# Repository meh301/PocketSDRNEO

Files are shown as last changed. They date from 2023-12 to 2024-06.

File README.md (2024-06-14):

# **Pocket SDR - An Open-Source GNSS SDR, ver. 2.1 NEO**

## **This project is now archived**
The NEO variant of the v2.1 PocketSDR was only meant to be a short-term solution for increasing international interest in the open source project. The official PocketSDR has now been updated to include USB-C, as well as several design improvements. Please refer to the official Github: https://github.com/tomojitakasu/PocketSDR

---

The NEO* variant of Professor 高須知二 (Tomoji Takasu)'s PocketSDR replaces the micro-B connector with type-C, fixes the LDO routing, adds an 0603 100 Ohm resistor at the output of the RF power divider as per the datasheet, and finally provides the option of either using a pin header or a Littlefuse MICROSMD010 for antenna power delivery.

Please note that due to the use of a type-C connector, the dimensions of the board are slightly larger than the original design.

## **Overview**

Pocket SDR is an open-source GNSS (Global Navigation Satellite System) receiver
based on SDR (software defined radio) technology. It consists of a RF front-end
device, some utilities for the device and GNSS-SDR APs (application programs)
written in Python and C. It supports almost all signals for GPS, GLONASS,
Galileo, QZSS, BeiDou, NavIC and SBAS.

The RF front-end device consists of 2 CH Maxim MAX2771 GNSS RF front-end IC
(LNA, mixer, filter, ADC, frequency synthesizer) and Cypress EZ-USB FX2LP USB
2.0 controller to connect to host PCs. The front-end CH1 is dedicated for GNSS
L1 band (1525 - 1610 MHz) and CH2 is for GNSS L2/L5/L6 band (1160 - 1290 MHz).
The frequency of the reference oscillator (TCXO) is 24.000 MHz and ADC sampling
frequency can be configured up to 24 MHz.

Pocket SDR contains some utility programs for the RF front-end device to
configure the device, capture and dump the digitized IF (inter-frequency) data.
These supports Windows, Linux and other environments.

Pocket SDR also provides GNSS-SDR APs to show the PSD (power spectrum density)
of captured IF data, search the GNSS signals, track these signals and decode
navigation data in them. The supported GNSS signals are as follows. These APs
are written in Python by very compact way. They are easily modified by users
to add user's unique algorithms.

GPS: L1C/A, L1CP, L1CD, L2CM, L5I, L5Q, GLONASS: L1C/A, L2C/A, L3OCD, L3OCP,
Galileo: E1B, E1C, E5aI, E5aQ, E5bI, E5bQ, E6B, E6C, QZSS: L1C/A, L1C/B, L1CP,
L1CD, L1S, L2CM, L5I, L5Q, L5SI, L5SQ, L6D, L6E, BeiDou: B1I, B1CP, B1CD, B2I,
B2aD, B2aP, B2bI, B3I, NavIC: L5-SPS, SBAS: L1C/A, L5I, L5Q

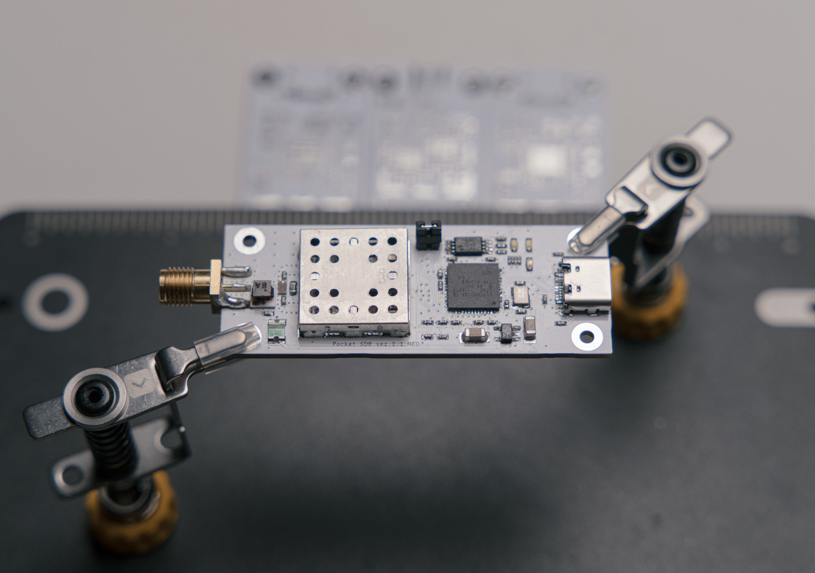
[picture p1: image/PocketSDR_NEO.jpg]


The introduction of Pocket SDR is shown in the following slides.

T.Takasu, An Open Source GNSS SDR: Development and Application, IPNTJ Next GNSS
Technology WG, Feb 21, 2022
(https://gpspp.sakura.ne.jp/paper2005/IPNTJ_NEXTWG_202202.pdf)

---

## **Package Structure**

```
PocketSDR --+-- bin     Pocket SDR utilities and APs binary programs for Windows
            +-- app     Pocket SDR utilities and APs source programs
            +-- src     Pocket SDR library source programs
            +-- python  Pocket SDR Python scripts
            +-- lib     External library for utilities and APs
            +-- conf    Configuration files for device settings
            +-- driver  Windows driver for EZ-USB FX2LP/FX3 (cyusb3.sys) ([4])
            +-- doc     Documents (ref {1], [2])
            +-- FW      Firmware source programs and images
            |   +-- cypress  Cypress libraries for EZ-USB firmware development
            |                (ref [4])
            +-- HW      Pocket SDR RF frontend CAD data and parts list
            |           (*.brd and *.sch are for Eagle, *.f3d is for Fusion 360)
            +-- image   Image files for documents
            +-- sample  Sample digital IF data captured by Pocket SDR
            +-- test    Test codes
```

---

## **Installation for Windows**

- Extract PocketSDR.zip to an appropriate directory <install_dir>.

- Attach Pocket SDR RF frontend to PC via USB cable.

- Install USB driver (CYUSB) for Pocket SDR RF frontend according to
  PocketSDR\driver\readme.txt.

- Add the Pocket SDR binary programs path (<install_dir>\PocketSDR\bin) to
  the command search path (Path) of Windows environment variables.

- Add the Pocket SDR Python scripts path (<install_dir>\PocketSDR\python) to
  the command search path (Path) of Windows environment variables.

- To rebuild the binary programs, you need MinGW64 and libusb-1.0 library.
  Refer MSYS2 (https://www.msys2.org/) for details.

- In MinGW64 environment, you need fftw3 library. To install fftw3 library.

```
    $ pacman -S mingw-w64-x86_64-fftw
```

---

## **Installation for Linux**

- Extract PocketSDR.zip to an appropriate directory <install_dir>.

```
    $ unzip PocketSDR.zip
```

- Install libusb-1.0 developtment package. For Ubuntu:

```
    $ sudo apt install libusb-1.0-0-dev
```

- Install libfftw3 developtment package. For Ubuntu:

```
    $ sudo apt install libfftw3-dev
```

- Move to the library directory, build libraries.

```
    $ cd <install_dir>/lib/build
    $ make
    $ make install
```

- Move to the source program directory, build utilities and APs.

```
    $ cd <install_dir>/app
    $ make
    $ make install
```

- Add the Pocket SDR binary programs path (<install_dir>/PocketSDR/bin) to
  the command search path.

- Usually you need to have root permission to access USB devices. So you add
  sudo to execute pocket_conf, pocket_dump like:

```
   $ sudo pocket_conf ../conf/pocket_L1L6_12MHz.conf
   $ sudo pocket_dump -t 10 ch1.bin ch2.bin
```

---

## **Utility Programs for RF frontend**

Pocket SDR contains the following utility programs.

- **pocket_conf**: SDR device configurator
- **pocket_scan**: Scan and list USB Devices
- **pocket_dump**: Capture and dump digital IF data of SDR device

For details, refer comment lines in src/pocket_conf.c, src/pocket_scan.c,
src/pocket_dump.c.

---

## **GNSS-SDR APs (Application Programs)**

Pocket SDR contains the following application programs for GNSS-SDR.

- **pocket_psd.py** : Plot PSD and histgrams of digital IF data
- **pocket_acq.py** : GNSS signal acquisition in digital IF data
- **pocket_trk.py** : GNSS signal tracking and navigation data decoding in digital IF data
- **pocket_snap.py**: Snapshot positioning with digital IF data
- **pocket_plot.py**: Plot GNSS signal tracking log by pocket_trk.py
- **pocket_acq** : C-version of pocket_acq.py (w/o graph plots)
- **pocket_trk** : C-version of pocket_trk.py (w/o graph plots)

For details, refer comment lines in python/pocket_psd.py, python/pocket_acq.py,
python/pocket_trk.py, python/pocket_snap.py and python/pocket_plot.py. You need
Python 3, Numpy, Scipy and matplotlib to execute Python scripts. pocket_trk.py
uses external shared libraries of LIBFEC [5] and RTKLIB [6] in lib/ directory.
These were built for Windows (64bit) and Linux for x86_64 CPU.

---

## **Execution Examples of Utility Programs and GNSS-SDR APs**

```
    $ pocket_conf
    ...
    $ pocket_conf conf/pocket_L1L6_12MHz.conf
    Pocket SDR device settings are changed.

    $ pocket_dump -t 5 ch1.bin ch2.bin
      TIME(s)    T   CH1(Bytes)   T   CH2(Bytes)   RATE(Ks/s)
          5.0    I     59768832  IQ    119537664      11922.8

    $ pocket_psd.py ch1.bin -f 12 -h
    $ pocket_acq.py ch1.bin -f 12 -fi 3 -sig L1CA -prn 1-32,193-199
    PRN   1: SIG= L1CA, COFF=  0.12817 ms, DOP=  3500 Hz, C/N0= 37.4 dB-Hz
    PRN   2: SIG= L1CA, COFF=  0.85242 ms, DOP= -3500 Hz, C/N0= 36.8 dB-Hz
    PRN   3: SIG= L1CA, COFF=  0.39400 ms, DOP= -2000 Hz, C/N0= 37.0 dB-Hz
    PRN   4: SIG= L1CA, COFF=  0.96692 ms, DOP=  2000 Hz, C/N0= 44.7 dB-Hz
    ...
    $ pocket_acq.py ch1.bin -f 12 -fi 3 -sig L1CA -prn 26

    $ pocket_acq.py ch1.bin -f 12 -fi 3 -sig L1CA -prn 26 -3d

    $ pocket_acq.py ch2.bin -f 12 -sig L6D -prn 194 -p

    $ pocket_trk.py L1_24M.bin -prn 1-32 -f 24 -fi 6
	  TIME(s)   SIG  PRN  STATE   LOCK(s)  C/N0 (dB-Hz)        COFF(ms)   DOP(Hz)   ADR(cyc)  SYNC #NAV #ERR
	    1.550  L1CA    1   LOCK     1.539  42.5 ||||||||      0.8017699    3218.8     4949.3  ---     0    0
	    0.011  L1CA    2   IDLE     0.000   0.0               0.0000000       0.0        0.0  ---     0    0
	    0.011  L1CA    3   IDLE     0.000   0.0               0.0000000       0.0        0.0  ---     0    0
	    0.011  L1CA    4   IDLE     0.000   0.0               0.0000000       0.0        0.0  ---     0    0
	    0.011  L1CA    5   IDLE     0.000   0.0               0.0000000       0.0        0.0  ---     0    0
	    0.011  L1CA    6   IDLE     0.000   0.0               0.0000000       0.0        0.0  ---     0    0
	    1.550  L1CA    7   LOCK     1.539  45.7 ||||||||||    0.6995059     582.8      901.5  ---     0    0
	    1.550  L1CA    8   LOCK     1.539  47.6 |||||||||||   0.0733506    -777.2    -1196.8  ---     0    0
	    0.011  L1CA    9   IDLE     0.000   0.0               0.0000000       0.0        0.0  ---     0    0
	    1.550  L1CA   10   LOCK     1.539  38.6 |||||         0.8658548      -6.2       -9.4  ---     0    0
	...
    $ pocket_trk.py L1_24M.bin -prn 194 -sig L1CA -f 24 -fi 6 -log trk.log  -p
    ...
    $ pocket_trk.py L5_24M.bin -prn 13 -sig E5AI -f 24 -log trk.log -p -ts 0.2
    ...
```









---

## **Rebuild F/W and Write F/W Image to Pocket SDR RF frontend**

- Install Cypress EZ-USB FX2LP Development Kit (ref [4]) to a Windows PC. As
  default, it is installed to C:\Cypress and C:\Keil.

- Execute Keil uVision2 (C:\Keil\UV2\uv2.exe).

- Execute Menu Project - Open Project, select <install_dir>\PocketSDR\FW\pocket_fw.Uv2>
  and open the project.

- Execute Menu Project - Rebuild all target files and you can get a F/W image
  as <install_dir>\PocketSDR\FW\pocket_fw.iic.

- Attach Pocket SDR RF frontend via USB cable to the PC.

- Execute USB Control Center (C:\Cypress\USB\CY3684_EZ-USB_FX2LP_DVK\1.1\Windows Applications\
  c_sharp\controlcenter\bin\Release\CyControl.exe).

- Select Cypress FX2LP Sample Device, execute menu Program - FX2 - 64KB EEPROM,
  select the F/W image <install_dir>\PocketSDR\FW\pocket_fw.iic and open it.

- If you see "Programming succeeded." in status bar, the F/W is properly written
  to PocketSDR.

- To use utility programs for Pocket SDR, you need to reinstall WinUSB driver for
  Pocket SDR. Refer "Installation for Windows" above.

---

## **References**

[1] Maxim integrated, MAX2771 Multiband Universal GNSS Receiver, July 2018

[2] Cypress, EZ-USB FX2LP USB Microcontroller High-Speed USB Peripheral
Controller, Rev. AB, December 6, 2018

[3] (deleted)

[4] Cypress, CY3684 EZ-USB FX2LP Development Kit
(https://www.cypress.com/documentation/development-kitsboards/cy3684-ez-usb-fx2lp-development-kit)

[5] https://github.com/quiet/libfec

[6] https://github.com/tomojitakasu/RTKLIB

---

## **History**

- 2021-10-20 0.1 1st draft version
- 2021-10-25 0.2 Add Rebuild F/W and Write F/W Image to PocketSDR
- 2021-12-01 0.3 Add and modify Python scripts
- 2021-12-25 0.4 Add and modify Python scripts
- 2022-01-05 0.5 Fix several problems.
- 2022-01-13 0.6 Add and modify Python scripts
- 2022-02-15 0.7 Improve performance, Add some Python scripts.
- 2022-07-08 0.8 Add C-version of pocket_acq.py and pocket_trk.py.

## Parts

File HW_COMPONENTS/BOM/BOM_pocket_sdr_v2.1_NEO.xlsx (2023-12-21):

DIGIKEY
Index | Manufacturer Part Number | Manufacturer Name | Description | Availability | Stock Status | Attrition % | Requested Quantity 1 | Pack Quantity 1 | Pack Type 1 | Digi-Key Part Number 1 | Unit Price 1 | Extended Price 1 | Minimum Order Quantity 1 | Customer Reference | Requested Part Number | Lead Weeks | Datasheet | Reference Designator | US Import Tariff | Note | Part Status | RoHS Status | Moisture Sensitivity Level (MSL) | ECCN | HTSUS | Country of Origin | Environmental Information | Original Part numbers | Image
1 | CY7C68013A-56LTXCT | Infineon Technologies | IC MCU USB PHERIPH FX2LP 56VQFN | 11046 | In Stock |  | 1 | 1 | Cut Tape (CT) | 448-CY7C68013A-56LTXCT-ND | 1886.00 | ¥1,886 | 1 |  | 428-4634-1-ND | 13 | https://www.infineon.com/dgdl/Infineon-CY7C68013A_CY7C68014A_CY7C68015A_CY7C68016A_EZ-USB_FX2LP_USB_Microcontroller_High-Speed_USB_Peripheral_Controller-DataS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 |  | - |  | Active | ROHS3 Compliant | 3 (168 Hours) | 3A991A3 | 8542.31.0001 | Philippines | https://www.cypress.com/file/199231/download | 428-4634-1-ND | https://mm.digikey.com/Volume0/opasdata/d220001/medias/images/582/56-VQFN-LT.jpg
2 | 24AA128T-I/ST | Microchip Technology | IC EEPROM 128KBIT I2C 8TSSOP | 30456 | In Stock |  | 1 | 1 | Cut Tape (CT) | 24AA128T-I/STCT-ND | 123 | ¥123 | 1 |  | 24AA128T-I/STCT-ND | 4 | https://ww1.microchip.com/downloads/en/DeviceDoc/24AA128-24LC128-24FC128-128K-I2C-Serial-EEPROM-DS.pdf |  | - |  | Active | ROHS3 Compliant | 1 (Unlimited) | EAR99 | 8542.32.0051 | Thailand | https://ww1.microchip.com/downloads/aemDocuments/documents/corporate-responsibilty/environmental/product-regulatory-information/Semiconductor_Prop_65_Statemen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|https://ww1.microchip.com/downloads/aemDocuments/documents/corporate-responsibilty/environmental/product-regulatory-information/Microchip_REACH_Statement.pdf|https://ww1.microchip.com/downloads/aemDocuments/documents/corporate-responsibilty/environmental/product-regulatory-information/Semiconductor_EnvCoC.pdf | 24AA128T-I/STCT-ND | https://mm.digikey.com/Volume0/opasdata/d220001/medias/images/5462/150~C04-086~ST~8.JPG
3 | RP111N331D-TR-FE | Nisshinbo Micro Devices Inc. | IC REG LINEAR 3.3V 500MA SOT23-5 | 9425 | In Stock |  | 1 | 1 | Cut Tape (CT) | 2129-RP111N331D-TR-FECT-ND | 174 | ¥174 | 1 |  | 2129-RP111N331D-TR-FECT-ND | 12 | https://www.nisshinbo-microdevices.co.jp/en/pdf/datasheet/rp111-ea.pdf |  | - |  | Active | ROHS3 Compliant | 1 (Unlimited) | EAR99 | 8542.39.0001 | Japan |  | 2129-RP111N331D-TR-FECT-ND | https://mm.digikey.com/Volume0/opasdata/d220001/medias/images/4376/MFG_SOT-23-5.jpg
4 | 830108340709 | Würth Elektronik | WE-XTAL QUARTZ CRYSTAL 24.0 MHZ; | 124 | In Stock |  | 1 | 1 | Cut Tape (CT) | 1923-830108340709CT-ND | 128 | ¥128 | 1 |  | 1923-830108340709CT-ND | 11 | https://www.we-online.com/catalog/datasheet/830108340709.pdf |  | May apply on shipments to the U.S. |  | Active | ROHS3 Compliant | Not Applicable | EAR99 | 8541.60.0060 | China | https://mm.digikey.com/Volume0/opasdata/d220001/medias/docus/744/Certificate_of_Compliance_ROHS.pdf | 1923-830108340709CT-ND | https://mm.digikey.com/Volume0/opasdata/d220001/medias/images/2832/MFG_XTAL_CFPX-180.jpg
5 | RC0402JR-0715KL | YAGEO | RES 15K OHM 5% 1/16W 0402 | 631681 | In Stock |  | 2 | 2 | Cut Tape (CT) | 311-15KJRCT-ND | 16 | ¥32 | 1 |  | 311-15KJRCT-ND | 18 | https://www.yageo.com/upload/media/product/app/datasheet/rchip/pyu-rc_group_51_rohs_l.pdf |  | May apply on shipments to the U.S. |  | Active | ROHS3 Compliant | 1 (Unlimited) | EAR99 | 8533.21.0030 | Taiwan | https://www.yageo.com/en/Download/Index/certificates#rchip | 311-15KJRCT-ND | https://mm.digikey.com/Volume0/opasdata/d220001/medias/images/4849/13_0402-%281005-metric%29.jpg
6 | RC0402JR-0710KL | YAGEO | RES 10K OHM 5% 1/16W 0402 | 28660058 | In Stock |  | 5 | 5 | Cut Tape (CT) | 311-10KJRCT-ND | 16 | ¥80 | 1 |  | 311-10KJRCT-ND | 18 | https://www.yageo.com/upload/media/product/app/datasheet/rchip/pyu-rc_group_51_rohs_l.pdf |  | - |  | Active | ROHS3 Compliant | 1 (Unlimited) | EAR99 | 8533.21.0030 | Taiwan | https://www.yageo.com/en/Download/Index/certificates#rchip | 311-10KJRCT-ND | https://mm.digikey.com/Volume0/opasdata/d220001/medias/images/4849/13_0402-%281005-metric%29.jpg
7 | RC0402JR-072K2L | YAGEO | RES 2.2K OHM 5% 1/16W 0402 | 1852 | In Stock |  | 2 | 2 | Cut Tape (CT) | 311-2.2KJRCT-ND | 16 | ¥32 | 1 |  | 311-2.2KJRCT-ND | 18 | https://www.yageo.com/upload/media/product/app/datasheet/rchip/pyu-rc_group_51_rohs_l.pdf |  | May apply on shipments to the U.S. |  | Active | ROHS3 Compliant | 1 (Unlimited) | EAR99 | 8533.21.0030 | Taiwan | https://www.yageo.com/en/Download/Index/certificates#rchip | 311-2.2KJRCT-ND | https://mm.digikey.com/Volume0/opasdata/d220001/medias/images/4849/13_0402-%281005-metric%29.jpg
8 | RC0402JR-07100KL | YAGEO | RES 100K OHM 5% 1/16W 0402 | 10781777 | In Stock |  | 1 | 1 | Cut Tape (CT) | 311-100KJRCT-ND | 16 | ¥16 | 1 |  | 311-100KJRCT-ND | 18 | https://www.yageo.com/upload/media/product/app/datasheet/rchip/pyu-rc_group_51_rohs_l.pdf |  | - |  | Active | ROHS3 Compliant | 1 (Unlimited) | EAR99 | 8533.21.0030 | Taiwan | https://www.yageo.com/en/Download/Index/certificates#rchip | 311-100KJRCT-ND | https://mm.digikey.com/Volume0/opasdata/d220001/medias/images/4849/13_0402-%281005-metric%29.jpg
9 | EXB-28V102JX | Panasonic Electronic Components | RES ARRAY 4 RES 1K OHM 0804 | 370304 | In Stock |  | 1 | 1 | Cut Tape (CT) | Y7102CT-ND | 16 | ¥16 | 1 |  | Y7102CT-ND | 19 | https://industrial.panasonic.com/cdbs/www-data/pdf/AOC0000/AOC0000C14.pdf |  | - |  | Active | ROHS3 Compliant | 1 (Unlimited) | EAR99 | 8533.21.0020 | Japan | https://industrial.panasonic.com/cdbs/www-cgi/auto-publishing.cgi?type=ROSU&region=WW&layer=4&cd=AOC0004 | Y7102CT-ND | https://mm.digikey.com/Volume0/opasdata/d220001/medias/images/519/EXBxxV.jpg
10 | KGM05AR71H471KH | KYOCERA AVX | CAP CER 470PF 50V X7R 0402 | 686118 | In Stock |  | 4 | 4 | Cut Tape (CT) | 478-KGM05AR71H471KHCT-ND | 16 | ¥64 | 1 |  | 478-1097-1-ND | 12 | https://datasheets.kyocera-avx.com/KGM_X7R.pdf |  | May apply on shipments to the U.S. |  | Active | ROHS3 Compliant | 1 (Unlimited) | EAR99 | 8532.24.0020 | China |  | 478-1097-1-ND | https://mm.digikey.com/Volume0/opasdata/d220001/medias/images/4848/478_0402-(1005-Metric)-0,56mm.jpg
11 | GJM1555C1H1R7BB01D | Murata Electronics | CAP CER 1.7PF 50V C0G/NP0 0402 | 17415 | In Stock |  | 1 | 1 | Cut Tape (CT) | 490-6074-1-ND | 16 | ¥16 | 1 |  | 490-6074-1-ND | 19 | https://search.murata.co.jp/Ceramy/image/img/A01X/G101/ENG/GJM1555C1H1R7BB01-01.pdf |  | - |  | Active | ROHS3 Compliant | 1 (Unlimited) | EAR99 | 8532.24.0020 | Singapore |  | 490-6074-1-ND | https://mm.digikey.com/Volume0/opasdata/d220001/medias/images/5447/490-Ceramic-Capacitor-Tan-Field.jpg
12 | CC0402BRNPO9BN1R1 | YAGEO | CAP CER 1.1PF 50V C0G/NPO 0402 | 56849 | In Stock |  | 1 | 1 | Cut Tape (CT) | 311-3321-1-ND | 16 | ¥16 | 1 |  | 311-3321-1-ND | 16 | https://www.yageo.com/upload/media/product/productsearch/datasheet/mlcc/UPY-GP_NP0_16V-to-50V_18.pdf |  | - |  | Active | ROHS3 Compliant | 1 (Unlimited) | EAR99 | 8532.24.0020 | Taiwan |  | 311-3321-1-ND | https://mm.digikey.com/Volume0/opasdata/d220001/medias/images/2392/0402(0^50 thickness).jpg
13 | UMK105CH751JVHF | Taiyo Yuden | CAP CER 750PF 50V CH 0402 | 17249 | In Stock |  | 2 | 2 | Cut Tape (CT) | 587-5098-1-ND | 16 | ¥32 | 1 |  | 587-5098-1-ND | 17 | https://www.yuden.co.jp/productdata/catalog/mlcc02_hq_e.pdf |  | May apply on shipments to the U.S. |  | Not For New Designs | ROHS3 Compliant | 1 (Unlimited) | EAR99 | 8532.24.0020 | China |  | 587-5098-1-ND | https://mm.digikey.com/Volume0/opasdata/d220001/medias/images/4845/587_0402-(1005-metric).jpg
14 | KGM05ACG1H150JH | KYOCERA AVX | CAP CER 15PF 50V C0G/NP0 0402 | 414920 | In Stock |  | 2 | 2 | Cut Tape (CT) | 478-KGM05ACG1H150JHCT-ND | 16 | ¥32 | 1 |  | 478-1072-1-ND | 12 | https://datasheets.kyocera-avx.com/C0GNP0-KGM.pdf |  | - |  | Active | ROHS3 Compliant | 1 (Unlimited) | EAR99 | 8532.24.0020 | Taiwan |  | 478-1072-1-ND | https://mm.digikey.com/Volume0/opasdata/d220001/medias/images/4848/478_0402-(1005-Metric)-0,56mm.jpg
15 | KGM05AR71C103KH | KYOCERA AVX | CAP CER 10000PF 16V X7R 0402 | 3994352 | In Stock |  | 3 | 3 | Cut Tape (CT) | 478-KGM05AR71C103KHCT-ND | 16 | ¥48 | 1 |  | 478-1114-1-ND | 12 | https://datasheets.kyocera-avx.com/KGM_X7R.pdf |  | May apply on shipments to the U.S. |  | Active | ROHS3 Compliant | 1 (Unlimited) | EAR99 | 8532.24.0020 | China |  | 478-1114-1-ND | https://mm.digikey.com/Volume0/opasdata/d220001/medias/images/4848/478_0402-(1005-Metric)-0,56mm.jpg
16 | KGM05AR71C104KH | KYOCERA AVX | CAP CER 0.1UF 16V X7R 0402 | 2523551 | In Stock |  | 14 | 14 | Cut Tape (CT) | 478-KGM05AR71C104KHCT-ND | 2.2 | ¥31 | 1 |  | 478-7888-1-ND | 12 | https://datasheets.kyocera-avx.com/KGM_X7R.pdf |  | May apply on shipments to the U.S. |  | Active | ROHS3 Compliant | 1 (Unlimited) | EAR99 | 8532.24.0020 | China |  | 478-7888-1-ND | https://mm.digikey.com/Volume0/opasdata/d220001/medias/images/4848/478_0402-(1005-Metric)-0,55mm.jpg
17 | KGM05ACG1H101JH | KYOCERA AVX | CAP CER 100PF 50V C0G/NP0 0402 | 1136945 | In Stock |  | 9 | 9 | Cut Tape (CT) | 478-KGM05ACG1H101JHCT-ND | 16 | ¥144 | 1 |  | 478-1082-1-ND | 12 | https://datasheets.kyocera-avx.com/C0GNP0-KGM.pdf |  | May apply on shipments to the U.S. |  | Active | ROHS3 Compliant | 1 (Unlimited) | EAR99 | 8532.24.0020 | Taiwan |  | 478-1082-1-ND | https://mm.digikey.com/Volume0/opasdata/d220001/medias/images/4848/478_0402-(1005-Metric)-0,56mm.jpg
18 | KGM05ACG1H120JH | KYOCERA AVX | CAP CER 12PF 50V C0G/NP0 0402 | 604115 | In Stock |  | 2 | 2 | Cut Tape (CT) | 478-KGM05ACG1H120JHCT-ND | 16 | ¥32 | 1 |  | 478-1071-1-ND | 12 | https://datasheets.kyocera-avx.com/C0GNP0-KGM.pdf |  | May apply on shipments to the U.S. |  | Active | ROHS3 Compliant | 1 (Unlimited) | EAR99 | 8532.24.0020 | Taiwan |  | 478-1071-1-ND | https://mm.digikey.com/Volume0/opasdata/d220001/medias/images/4848/478_0402-(1005-Metric)-0,56mm.jpg
19 | KGM05AR51A105KH | KYOCERA AVX | CAP CER 1UF 10V X5R 0402 | 2583923 | In Stock |  | 1 | 1 | Cut Tape (CT) | 478-KGM05AR51A105KHCT-ND | 17 | ¥17 | 1 |  | 478-4596-1-ND | 12 | https://datasheets.kyocera-avx.com/cx5r-KGM.pdf |  | May apply on shipments to the U.S. |  | Active | ROHS3 Compliant | 1 (Unlimited) | EAR99 | 8532.24.0020 | Taiwan |  | 478-4596-1-ND | https://mm.digikey.com/Volume0/opasdata/d220001/medias/images/4848/478_0402-(1005-Metric)-0,56mm.jpg
20 | CL31B106MOHNNNE | Samsung Electro-Mechanics | CAP CER 10UF 16V X7R 1206 | 711406 | In Stock |  | 2 | 2 | Cut Tape (CT) | 1276-6641-1-ND | 32 | ¥64 | 1 |  | 1276-6641-1-ND | 22 | https://www.samsungsem.com/resources/file/global/support/product_catalog/MLCC.pdf |  | - |  | Active | ROHS3 Compliant | 1 (Unlimited) | EAR99 | 8532.24.0020 | Philippines | https://www.samsungsem.com/files/fileDown.do?key=ed1dfdfa-645e-4252-b707-17f9b1502dd1|https://www.samsungsem.com/global/support/certificate/product-stewardship.do | 1276-6641-1-ND | https://mm.digikey.com/Volume0/opasdata/d220001/medias/images/2537/Ceramic-Capacitor-CL-Series.jpg
21 | LQW18AN5N6D00D | Murata Electronics | FIXED IND 5.6NH 750MA 0.082OHM | 24875 | In Stock |  | 1 | 1 | Cut Tape (CT) | 490-1164-1-ND | 24 | ¥24 | 1 |  | 490-1164-1-ND | 15 | https://search.murata.co.jp/Ceramy/image/img/P02/JELF243A-0024.pdf |  | - |  | Active | ROHS3 Compliant | 1 (Unlimited) | EAR99 | 8504.50.8000 | Malaysia |  | 490-1164-1-ND | https://mm.digikey.com/Volume0/opasdata/d220001/medias/images/4845/MFG_490_LQW18AS4N3G0CD.jpg
22 | LQW18AN8N4C8ZD | Murata Electronics | FIXED IND 8.4NH 1.6A 0.052OHM SM | 5276 | In Stock |  | 1 | 1 | Cut Tape (CT) | 490-15752-1-ND | 40 | ¥40 | 1 |  | 490-15752-1-ND | 15 | https://search.murata.co.jp/Ceramy/image/img/P02/JELF243A-9133.pdf |  | - |  | Active | ROHS3 Compliant | 1 (Unlimited) | EAR99 | 8504.50.8000 | Japan |  | 490-15752-1-ND | https://mm.digikey.com/Volume0/opasdata/d220001/medias/images/4845/MFG_490_LQW18AS4N3G0CD.jpg
23 | APT1608SGC | Kingbright | LED GREEN CLEAR CHIP SMD | 109960 | In Stock |  | 1 | 1 | Cut Tape (CT) | 754-1121-1-ND | 46 | ¥46 | 1 |  | 754-1121-1-ND | 8 | https://www.KingbrightUSA.com/images/catalog/SPEC/APT1608SGC.pdf |  | - |  | Active | ROHS3 Compliant | 3 (168 Hours) | EAR99 | 8541.41.0000 | China | https://www.kingbrightusa.com/webimages/certificate/REACH.pdf|https://www.KingbrightUSA.com/webimages/certificate/Kingbright%20RoHS%20CoC.PDF | 754-1121-1-ND | https://mm.digikey.com/Volume0/opasdata/d220001/medias/images/2392/APT1608 SERIES.jpg
24 | QBLP601-IW | QT Brightek (QTB) | LED WHITE DIFFUSED 0603 SMD | 421990 | In Stock |  | 2 | 2 | Cut Tape (CT) | 1516-1057-1-ND | 60 | ¥120 | 1 |  | 1516-1057-1-ND | 5 | https://www.qt-brightek.com/datasheet/QBLP601_series.pdf |  | - |  | Active | ROHS3 Compliant | 3 (168 Hours) | EAR99 | 8541.41.0000 | China | http://mm.digikey.com/Volume0/opasdata/d220001/medias/docus/40/RoHS2_Declaration_of_Conformity.pdf | 1516-1057-1-ND | https://mm.digikey.com/Volume0/opasdata/d220001/medias/images/668/MFG_QBLP601-IW.jpg
25 | M22-2510205 | Harwin Inc. | CONN HEADER VERT 2POS 2MM | 5792 | In Stock |  | 1 | 1 | Bulk | 952-1311-ND | 32 | ¥32 | 1 |  | 952-1311-ND | 17 | https://cdn.harwin.com/pdfs/Harwin_Datasheet-INDESS.pdf |  | - |  | Active | ROHS3 Compliant | 1 (Unlimited) | EAR99 | 8536.69.4040 | Taiwan | https://cdn.harwin.com/pdfs/HF-338_REACH_Statement.pdf|https://www.harwin.com/products/M22-2510205/rohs-compliance-statement/ | 952-1311-ND | https://mm.digikey.com/Volume0/opasdata/d220001/medias/images/375/MFG_M22-2510205.jpg
26 | SPN02SYBN-RC | Sullins Connector Solutions | CONN SHUNT 2MM OPEN TOP 2PS GOLD | 70450 | In Stock |  | 1 | 1 | Bulk | S3404-ND | 21 | ¥21 | 1 |  | S3404-ND | 11 | https://s3.amazonaws.com/catalogspreads-pdf/PAGE127%202mm%20JUMPER.pdf |  | - |  | Active | ROHS3 Compliant | 1 (Unlimited) | EAR99 | 8536.69.4040 | Taiwan | https://www.sullinscorp.com/wp-content/uploads/2021/08/Sullins-REACH-219-SVHC-Compliant-Statement.pdf|https://www.sullinscorp.com/wp-content/uploads/2019/03/Sullins-RoHS-Compliant-Statement.pdf | S3404-ND | https://mm.digikey.com/Volume0/opasdata/d220001/medias/images/1007/SPN02SYBN-RC.jpg
27 | BMI-S-202-F | Laird Technologies EMI | RF SHIELD 0.65" X 0.65" SOLDER | 103242 | In Stock |  | 1 | 1 | Cut Tape (CT) | 903-1051-1-ND | 316 | ¥316 | 1 |  | 903-1051-1-ND | 12 | https://www.laird.com/sites/default/files/bmi-s-202-sales.pdf |  | - |  | Active | ROHS3 Compliant | 1 (Unlimited) | EAR99 | 8529.90.9800 | Mexico |  | 903-1051-1-ND | https://mm.digikey.com/Volume0/opasdata/d220001/medias/images/4848/903_BMI-S-202-F.jpg
28 | BMI-S-202-C | Laird Technologies EMI | RF SHIELD 0.668"X0.668" SNAP FIT | 164218 | In Stock |  | 1 | 1 | Bulk | 903-1014-ND | 283 | ¥283 | 1 |  | 903-1014-ND | 12 | https://www.laird.com/sites/default/files/bmi-s-202-sales.pdf |  | - |  | Active | ROHS3 Compliant | 1 (Unlimited) | EAR99 | 8529.90.9800 | Mexico |  | 903-1014-ND | https://mm.digikey.com/Volume0/opasdata/d220001/medias/images/4843/903_BMI-S-202-C.jpg
29 | RC0402FR-135K1L | YAGEO | RES 5.1K OHM 1% 1/16W 0402 | 188038 | In Stock |  | 2 | 2 | Cut Tape (CT) | 13-RC0402FR-135K1LCT-ND | 16 | ¥32 | 1 |  | 13-RC0402FR-135K1LCT-ND | 18 | https://www.yageo.com/upload/media/product/productsearch/datasheet/rchip/PYu-RC_Group_51_RoHS_L_12.pdf |  | - |  | Active | ROHS3 Compliant | 1 (Unlimited) | EAR99 | 8533.21.0030 | Taiwan | https://www.yageo.com/en/Download/Index/certificates#rchip | 13-RC0402FR-135K1LCT-ND | https://mm.digikey.com/Volume0/opasdata/d220001/medias/images/4849/13_0402-(1005-metric).jpg
30 | RC0603FR-07100RL | YAGEO | RES 100 OHM 1% 1/10W 0603 | 3424961 | In Stock |  | 1 | 1 | Cut Tape (CT) | 311-100HRCT-ND | 16 | ¥16 | 1 |  | 311-100HRCT-ND | 18 | https://www.yageo.com/upload/media/product/app/datasheet/rchip/pyu-rc_group_51_rohs_l.pdf |  | May apply on shipments to the U.S. |  | Active | ROHS3 Compliant | 1 (Unlimited) | EAR99 | 8533.21.0030 | Taiwan | https://www.yageo.com/en/Download/Index/certificates#rchip | 311-100HRCT-ND | https://mm.digikey.com/Volume0/opasdata/d220001/medias/images/4848/13_0603-%281608-metric%29.jpg
31 | MICROSMD010F-2 | Littelfuse Inc. | PTC RESET FUSE 30V 100MA 1210 | 82922 | In Stock |  | 1 | 1 | Cut Tape (CT) | MICROSMD010F-2CT-ND | 55.00000 | ¥55 | 1 |  | MICROSMD010F-2CT-ND | 11 | https://www.littelfuse.com/~/media/electronics/product_specifications/resettable_ptcs/littelfuse_ptc_microsmd010f_2_product_specification.pdf.pdf |  | May apply on shipments to the U.S. |  | Active | ROHS3 Compliant | 2A (4 Weeks) | EAR99 | 8533.40.8070 | China |  | MICROSMD010F-2CT-ND | https://mm.digikey.com/Volume0/opasdata/d220001/medias/images/3007/MICROSMDF SERIES.jpg
MOUSER
Line No. | Mouser #: | Mfr. #: | Description | Order Qty. | Ext. (JPY) | Price (JPY) | link
1 | 620-PD0922J5050S2HF | PD0922J5050S2HF | Signal Conditioning Signal Conditioning 950-2150MHz 50 Ohm IL=.7dB | 1 | ¥137.5 | ¥137.5 | https://www.mouser.jp/ProductDetail/620-PD0922J5050S2HF
2 | 732-TG252S24MCGNNM3 | TG2520SMN 24.0000M-MCGNNM3 | TCXO Oscillators TCXO Oscillators TG2520SMN 24.0000M-MCGNNM3: TCXO 2.8V-3.3V +/-0.5PPM -40-85C NON O/E250TR | 1 | ¥501.8 | ¥501.8 | https://www.mouser.jp/ProductDetail/732-TG252S24MCGNNM3
3 | 700-MAX2771ETI+ | MAX2771ETI+ | RF Receiver Multiband Universal GNSS Receiver | 2 | ¥1631 | ¥1631 | https://www.mouser.jp/ProductDetail/Analog-Devices-Maxim-Integrated/MAX2771ETI%2b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
MINI-CIRCUITS
Index | Manufacturer Part Number | Description | Order Qty. | Minimum order quantity | Unit Price (USD) | link
1 | TCBT-2R5G+ | BIAS TEE / SURF MT / RoHS | 1 | 10 | $8.79 | https://www.minicircuits.com/WebStore/dashboard.html?model=TCBT-2R5G%2B

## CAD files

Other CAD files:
HW/ARCHIVE_EAGLE/pocket_sdr_case.f3d

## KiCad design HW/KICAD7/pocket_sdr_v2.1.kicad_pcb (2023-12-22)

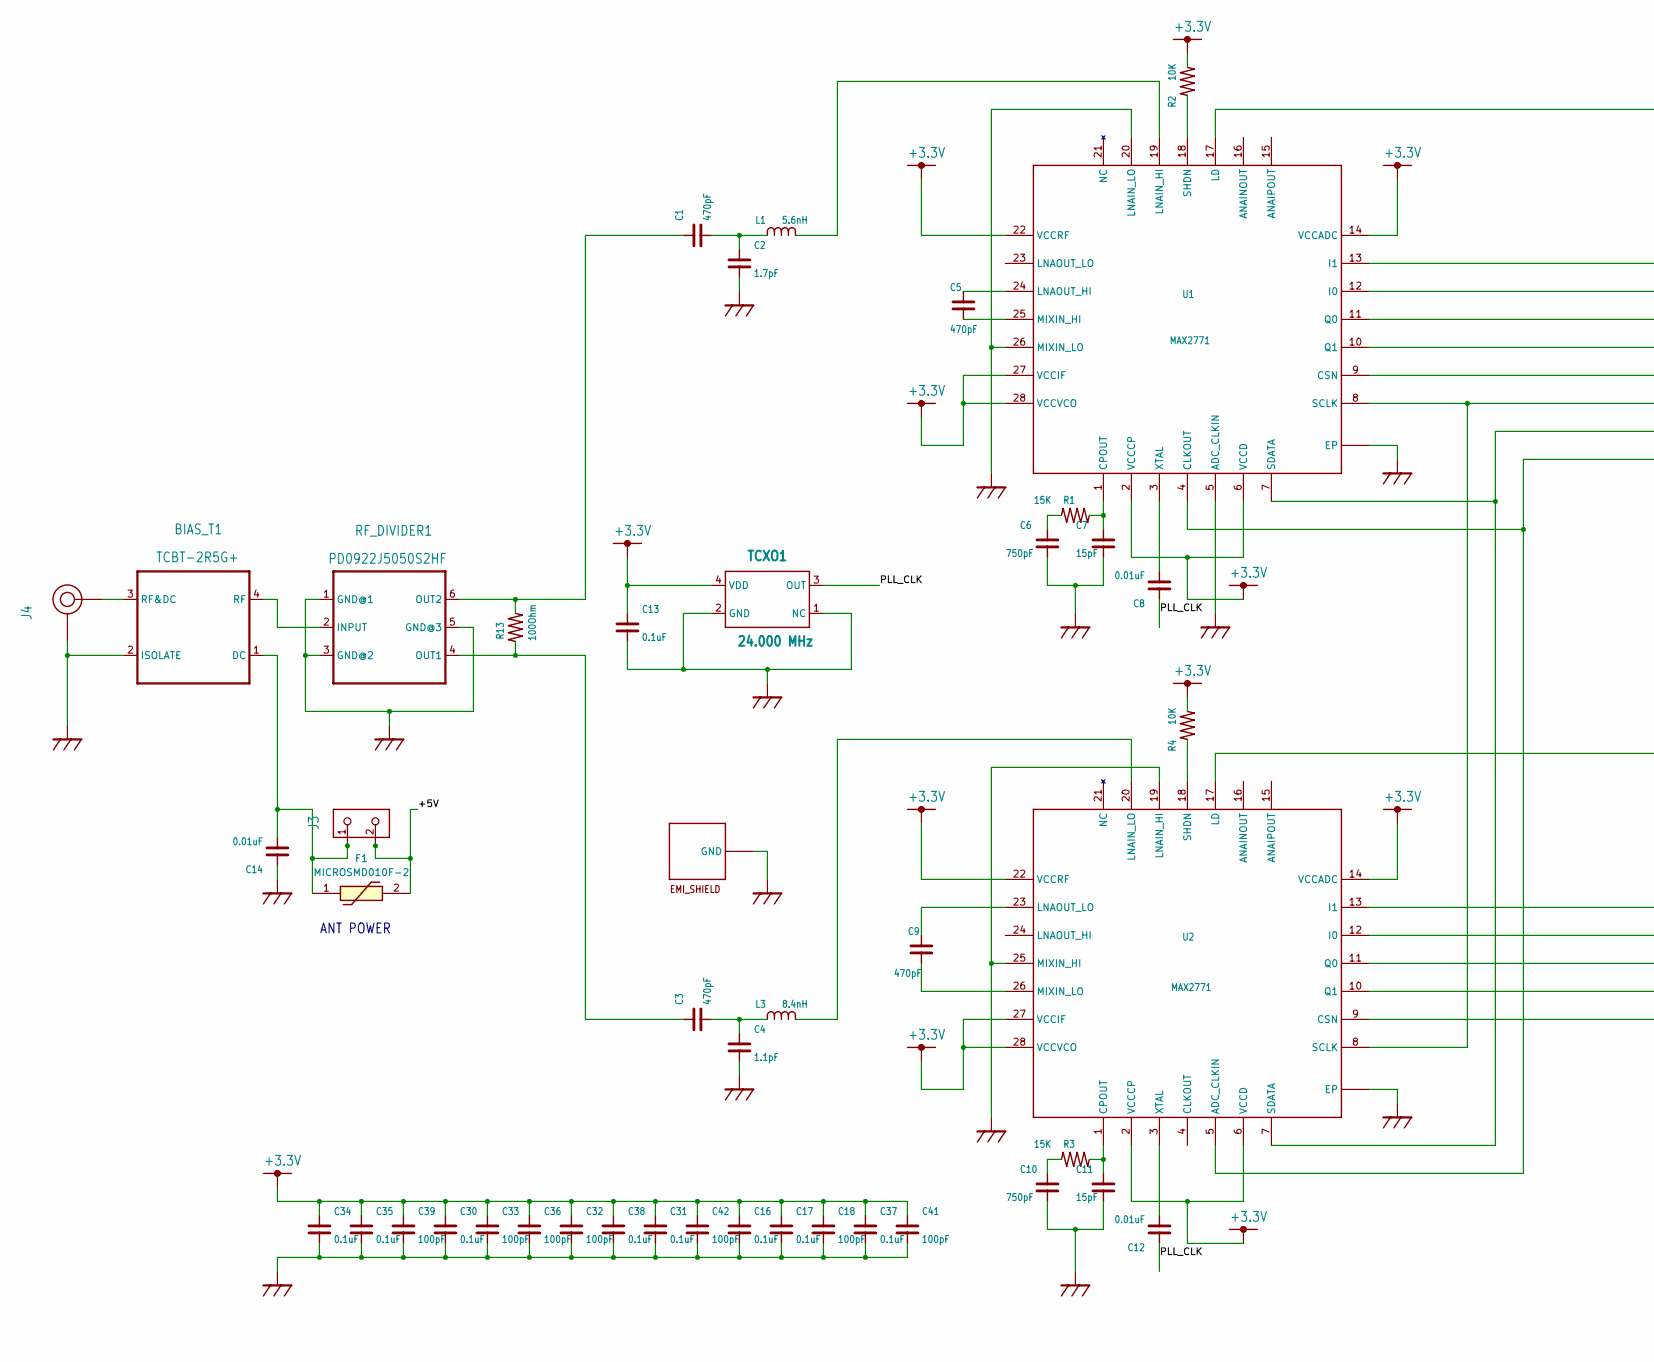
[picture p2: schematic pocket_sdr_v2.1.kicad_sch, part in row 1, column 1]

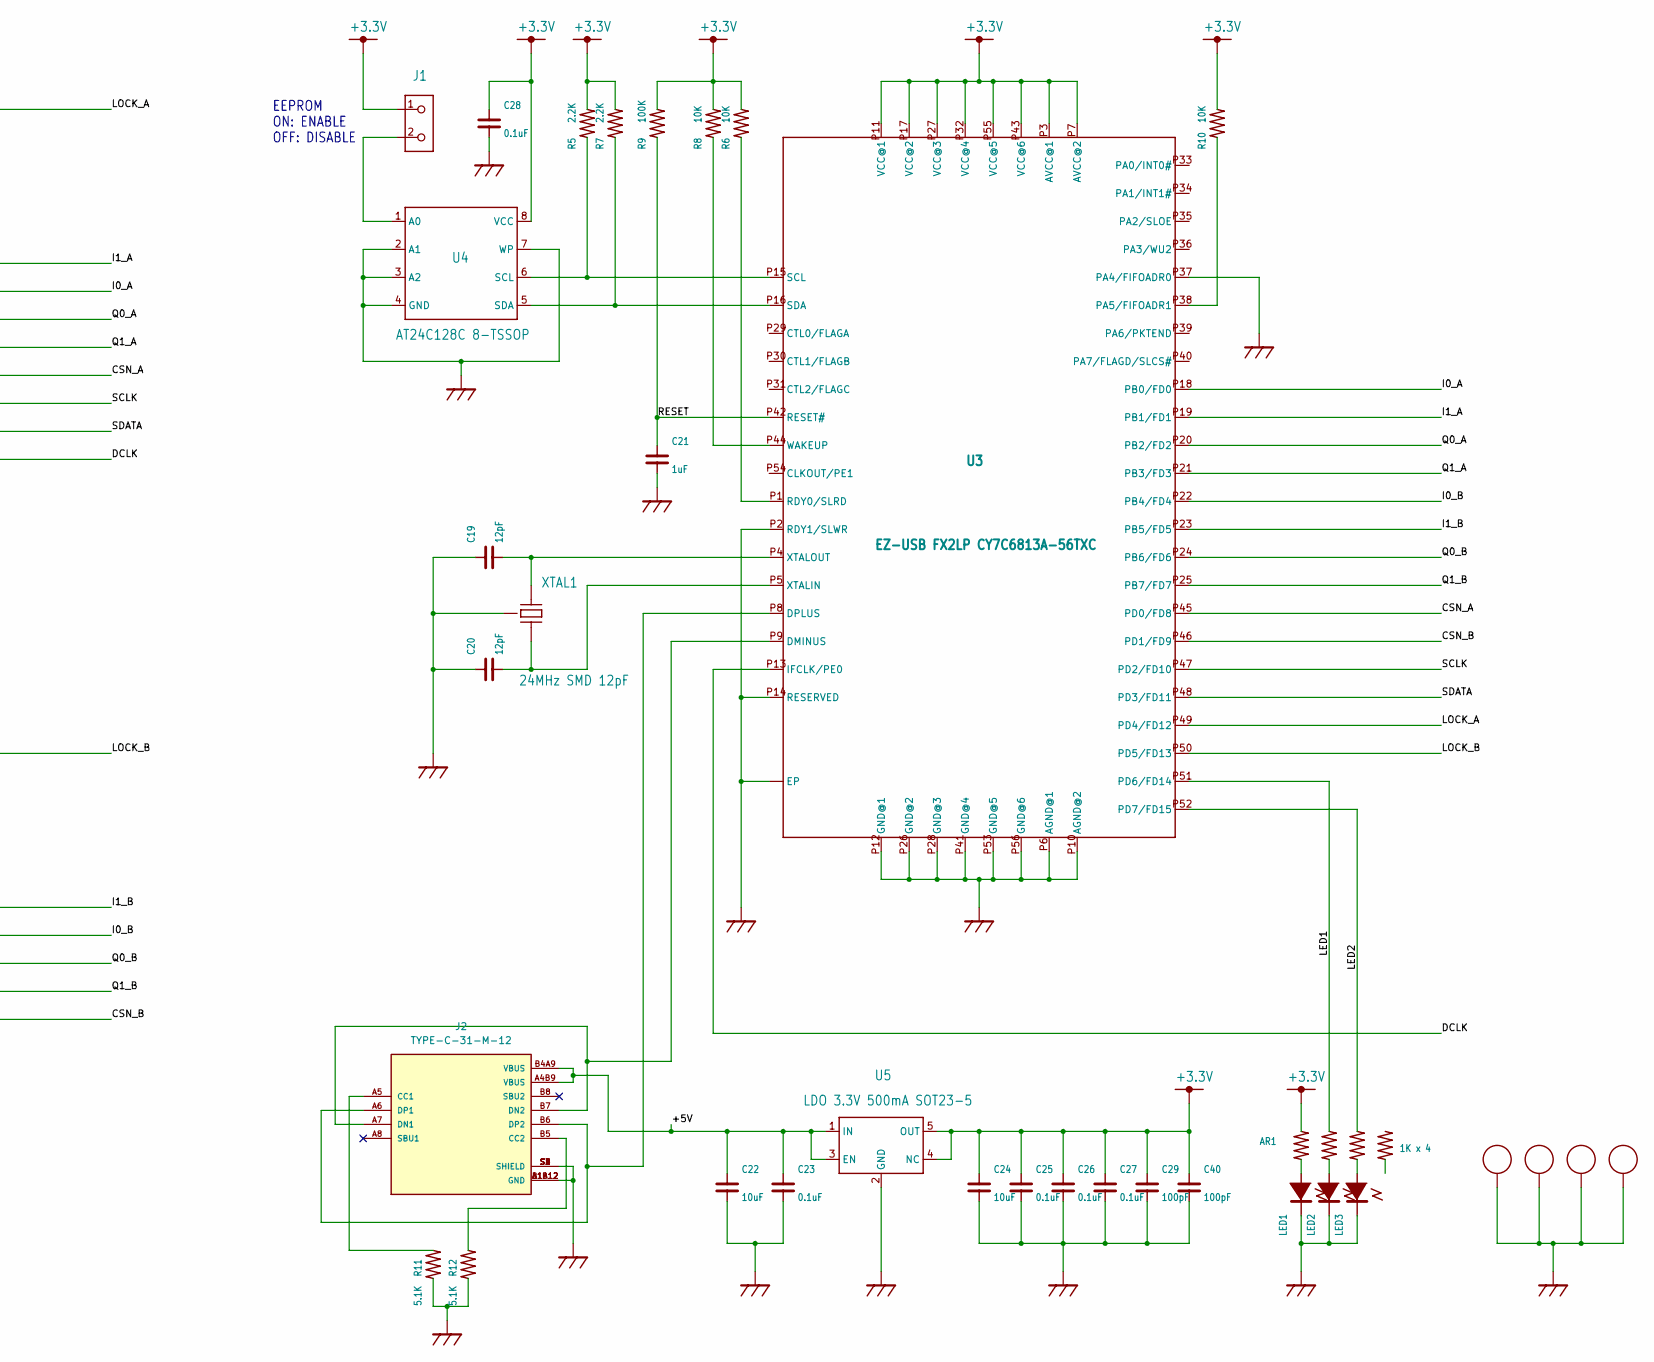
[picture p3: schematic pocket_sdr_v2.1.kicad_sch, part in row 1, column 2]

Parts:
AR1: 1K x 4; EXB28V
BIAS_T1: TCBT-2R5G+; BIAS_T
C1, C3, C5, C9: 470pF; C1005
C2: 1.7pF; C1005
C4: 1.1pF; C1005
C6, C10: 750pF; C1005
C7, C11: 15pF; C1005
C8, C12, C14: 0.01uF; C1005
C13, C16, C17, C23, C25, C26, C27, C28, C30, C31, C34, C35, C37, C38: 0.1uF; C1005
C18, C29, C32, C33, C36, C39, C40, C41, C42: 100pF; C1005
C19, C20: 12pF; C1005
C21: 1uF; C1005
C22, C24: 10uF; C3225
F1: MICROSMD010F-2; MICROSMD175F2; Manufacturer_Part_Number MICROSMD010F-2; Mouser Part Number 650-MICROSMD010F-2
J1, J3: PIN HEADER 2MM 2P; PINH-2MM-2P
J2: TYPE-C-31-M-12; HRO_TYPE-C-31-M-12; PARTREV A
J4: SMA JACK EDGE MNT; SMA-ANG
L1: 5.6nH; C1608
L3: 8.4nH; C1608
LED1: LED1608 GREEN; LED_1608
LED2, LED3: LED1608 BLUE; LED_1608
R1, R3: 15K; C1005
R2, R4, R6, R8, R10: 10K; C1005
R5, R7: 2.2K; C1005
R9: 100K; C1005
R11, R12: 5.1K; C1005
R13: 100Ohm; C_0603_1608Metric
RF-SHEILD-CASE1: BMI-S-202-F BMI-S-202-C; BMI-S-202
RF_DIVIDER1: PD0922J5050S2HF; RF_DIV
TCXO1: 24.000 MHz; TCXO
U1, U2: MAX2771; TQFN28
U3: EZ-USB FX2LP CY7C6813A-56TXC; QFN56
U4: AT24C128C 8-TSSOP; TSSOP_8P
U5: LDO 3.3V 500mA SOT23-5; SOT23
XTAL1: 24MHz SMD 12pF; XTAL_SMD

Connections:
+3.3V: AR1.2, C13.1, C16.1, C17.1, C18.1, C24.P$1 (1), C25.1, C26.1, C27.1, C28.1, C29.1, C30.1, C31.1, C32.1, C33.1, C34.1, C35.1, C36.1, C37.1, C38.1, C39.1, C40.1, C41.1, C42.1, J1.1, R2.2, R4.2, R5.2, R6.2, R7.2, R8.2, R9.2, R10.2, TCXO1.4 (VDD), U1.2 (VCCCP), U1.6 (VCCD), U1.14 (VCCADC), U1.22 (VCCRF), U1.27 (VCCIF), U1.28 (VCCVCO), U2.2 (VCCCP), U2.6 (VCCD), U2.14 (VCCADC), U2.22 (VCCRF), U2.27 (VCCIF), U2.28 (VCCVCO), U3.P3 (AVCC@1), U3.P7 (AVCC@2), U3.P11 (VCC@1), U3.P17 (VCC@2), U3.P27 (VCC@3), U3.P32 (VCC@4), U3.P43 (VCC@6), U3.P55 (VCC@5), U4.8 (VCC), U5.4 (NC), U5.5 (OUT)
/+5V: C22.P$1 (1), C23.1, F1.2, J2.A4B9 (VBUS), J2.B4A9 (VBUS), J3.2, U5.1 (IN), U5.3 (EN)
/CSN_A: U1.9 (CSN), U3.P45 (PD0/FD8)
/CSN_B: U2.9 (CSN), U3.P46 (PD1/FD9)
/DCLK: U1.4 (CLKOUT), U2.5 (ADC_CLKIN), U3.P13 (IFCLK/PE0)
/I0_A: U1.12 (I0), U3.P18 (PB0/FD0)
/I0_B: U2.12 (I0), U3.P22 (PB4/FD4)
/I1_A: U1.13 (I1), U3.P19 (PB1/FD1)
/I1_B: U2.13 (I1), U3.P23 (PB5/FD5)
/LED1: AR1.4, U3.P51 (PD6/FD14)
/LED2: AR1.6, U3.P52 (PD7/FD15)
/LOCK_A: U1.17 (LD), U3.P49 (PD4/FD12)
/LOCK_B: U2.17 (LD), U3.P50 (PD5/FD13)
/PLL_CLK: C8.1, C12.1, TCXO1.3 (OUT)
/Q0_A: U1.11 (Q0), U3.P20 (PB2/FD2)
/Q0_B: U2.11 (Q0), U3.P24 (PB6/FD6)
/Q1_A: U1.10 (Q1), U3.P21 (PB3/FD3)
/Q1_B: U2.10 (Q1), U3.P25 (PB7/FD7)
/RESET: C21.1, R9.1, U3.P42 (RESET#)
/SCLK: U1.8 (SCLK), U2.8 (SCLK), U3.P47 (PD2/FD10)
/SDATA: U1.7 (SDATA), U2.7 (SDATA), U3.P48 (PD3/FD11)
GND: BIAS_T1.2 (ISOLATE), C2.1, C4.2, C6.2, C7.2, C10.2, C11.2, C13.2, C14.1, C16.2, C17.2, C18.2, C19.1, C20.1, C21.2, C22.P$2 (2), C23.2, C24.P$2 (2), C25.2, C26.2, C27.2, C28.2, C29.2, C30.2, C31.2, C32.2, C33.2, C34.2, C35.2, C36.2, C37.2, C38.2, C39.2, C40.2, C41.2, C42.2, J2.A1B12 (GND), J2.B1A12 (GND), J2.S1 (SHIELD), J2.S2 (SHIELD), J2.S3 (SHIELD), J2.S4 (SHIELD), J4.P2 (GND), J4.P3 (GND), J4.P4 (GND), J4.P5 (GND), LED1.2, LED2.2, LED3.2, R11.1, R12.1, RF-SHEILD-CASE1.P1 (GND), RF-SHEILD-CASE1.P2 (GND), RF-SHEILD-CASE1.P3 (GND), RF-SHEILD-CASE1.P4 (GND), RF-SHEILD-CASE1.P5 (GND), RF-SHEILD-CASE1.P6 (GND), RF-SHEILD-CASE1.P7 (GND), RF-SHEILD-CASE1.P8 (GND), RF-SHEILD-CASE1.P9 (GND), RF-SHEILD-CASE1.P10 (GND), RF-SHEILD-CASE1.P11 (GND), RF-SHEILD-CASE1.P12 (GND), RF_DIVIDER1.1 (GND@1), RF_DIVIDER1.3 (GND@2), RF_DIVIDER1.5 (GND@3), TCXO1.1 (NC), TCXO1.2 (GND), U1.5 (ADC_CLKIN), U1.20 (LNAIN_LO), U1.26 (MIXIN_LO), U1.C1 (EP), U1.C2 (EP), U1.C3 (EP), U1.C4 (EP), U1.EP, U1.V1 (EP), U1.V2 (EP), U1.V3 (EP), U1.V4 (EP), U1.V5 (EP), U1.V6 (EP), U1.V7 (EP), U1.V8 (EP), U1.V9 (EP), U2.19 (LNAIN_HI), U2.25 (MIXIN_HI), U2.C1 (EP), U2.C2 (EP), U2.C3 (EP), U2.C4 (EP), U2.EP, U2.V1 (EP), U2.V2 (EP), U2.V3 (EP), U2.V4 (EP), U2.V5 (EP), U2.V6 (EP), U2.V7 (EP), U2.V8 (EP), U2.V9 (EP), U3.EP1 (EP), U3.EP2 (EP), U3.EP3 (EP), U3.EP4 (EP), U3.EP5 (EP), U3.P2 (RDY1/SLWR), U3.P6 (AGND@1), U3.P10 (AGND@2), U3.P12 (GND@1), U3.P14 (RESERVED), U3.P26 (GND@2), U3.P28 (GND@3), U3.P37 (PA4/FIFOADR0), U3.P41 (GND@4), U3.P53 (GND@5), U3.P56 (GND@6), U3.P$1 (EP), U3.P$2 (EP), U3.P$3 (EP), U3.P$4 (EP), U3.P$5 (EP), U3.P$6 (EP), U3.P$7 (EP), U3.P$8 (EP), U3.P$9 (EP), U3.P$10 (EP), U3.P$11 (EP), U3.P$12 (EP), U3.P$13 (EP), U3.P$14 (EP), U3.P$15 (EP), U3.P$16 (EP), U3.P$17 (EP), U3.P$18 (EP), U3.P$19 (EP), U3.P$20 (EP), U4.2 (A1), U4.3 (A2), U4.4 (GND), U4.7 (WP), U5.2 (GND), XTAL1.P2 (GND), XTAL1.P4 (GND); also elsewhere on the board
unnamed: AR1.1, LED1.1 (+)
unnamed: AR1.3, LED2.1 (+)
unnamed: AR1.5, LED3.1 (+)
unnamed: BIAS_T1.1 (DC), C14.2, F1.1, J3.1
unnamed: BIAS_T1.3 (RF&DC), J4.P1 (RF)
unnamed: BIAS_T1.4 (RF), RF_DIVIDER1.2 (INPUT)
unnamed: J1.2, U4.1 (A0)
unnamed: J2.A5 (CC1), R11.2
unnamed: J2.B5 (CC2), R12.2
unnamed: J2.A7 (DN1), J2.B7 (DN2), U3.P9 (DMINUS)
unnamed: J2.A6 (DP1), J2.B6 (DP2), U3.P8 (DPLUS)
unnamed: C1.2, C2.2, L1.1
unnamed: L1.2, U1.19 (LNAIN_HI)
unnamed: C3.2, C4.1, L3.1
unnamed: L3.2, U2.20 (LNAIN_LO)
unnamed: C6.1, R1.1
unnamed: C7.1, R1.2, U1.1 (CPOUT)
unnamed: R2.1, U1.18 (SHDN)
unnamed: C10.1, R3.1
unnamed: C11.1, R3.2, U2.1 (CPOUT)
unnamed: R4.1, U2.18 (SHDN)
unnamed: R5.1, U3.P15 (SCL), U4.6 (SCL)
unnamed: R6.1, U3.P1 (RDY0/SLRD)
unnamed: R7.1, U3.P16 (SDA), U4.5 (SDA)
unnamed: R8.1, U3.P44 (WAKEUP)
unnamed: R10.1, U3.P38 (PA5/FIFOADR1)
unnamed: C3.1, R13.1, RF_DIVIDER1.4 (OUT1)
unnamed: C1.1, R13.2, RF_DIVIDER1.6 (OUT2)
unnamed: C5.1, U1.24 (LNAOUT_HI)
unnamed: C5.2, U1.25 (MIXIN_HI)
unnamed: C8.2, U1.3 (XTAL)
unnamed: C9.1, U2.23 (LNAOUT_LO)
unnamed: C9.2, U2.26 (MIXIN_LO)
unnamed: C12.2, U2.3 (XTAL)
unnamed: C20.2, U3.P5 (XTALIN), XTAL1.P3 (XTAL2)
unnamed: C19.2, U3.P4 (XTALOUT), XTAL1.P1 (XTAL1)

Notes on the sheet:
ANT POWER
EEPROM ON: ENABLE OFF: DISABLE

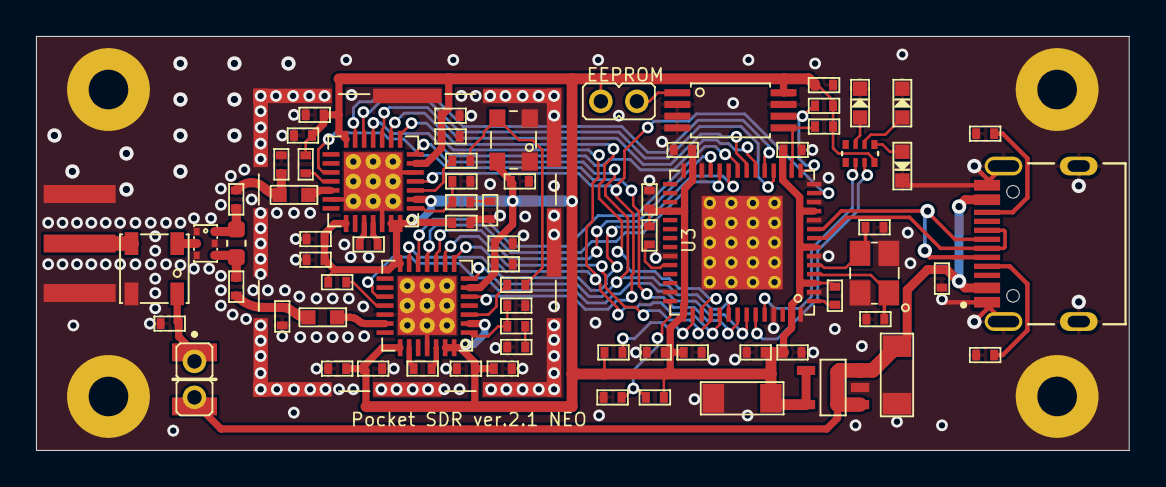
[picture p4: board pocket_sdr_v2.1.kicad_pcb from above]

Board: 2 copper layers, 60.7 x 23.0 mm, 79 parts (0 on the bottom side), 58 nets.

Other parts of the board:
U$53, U$54, U$55, U$58: CPAD_2.2MM

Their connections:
GND: U$53.EP, U$54.EP, U$55.EP, U$58.EP; also elsewhere on the board

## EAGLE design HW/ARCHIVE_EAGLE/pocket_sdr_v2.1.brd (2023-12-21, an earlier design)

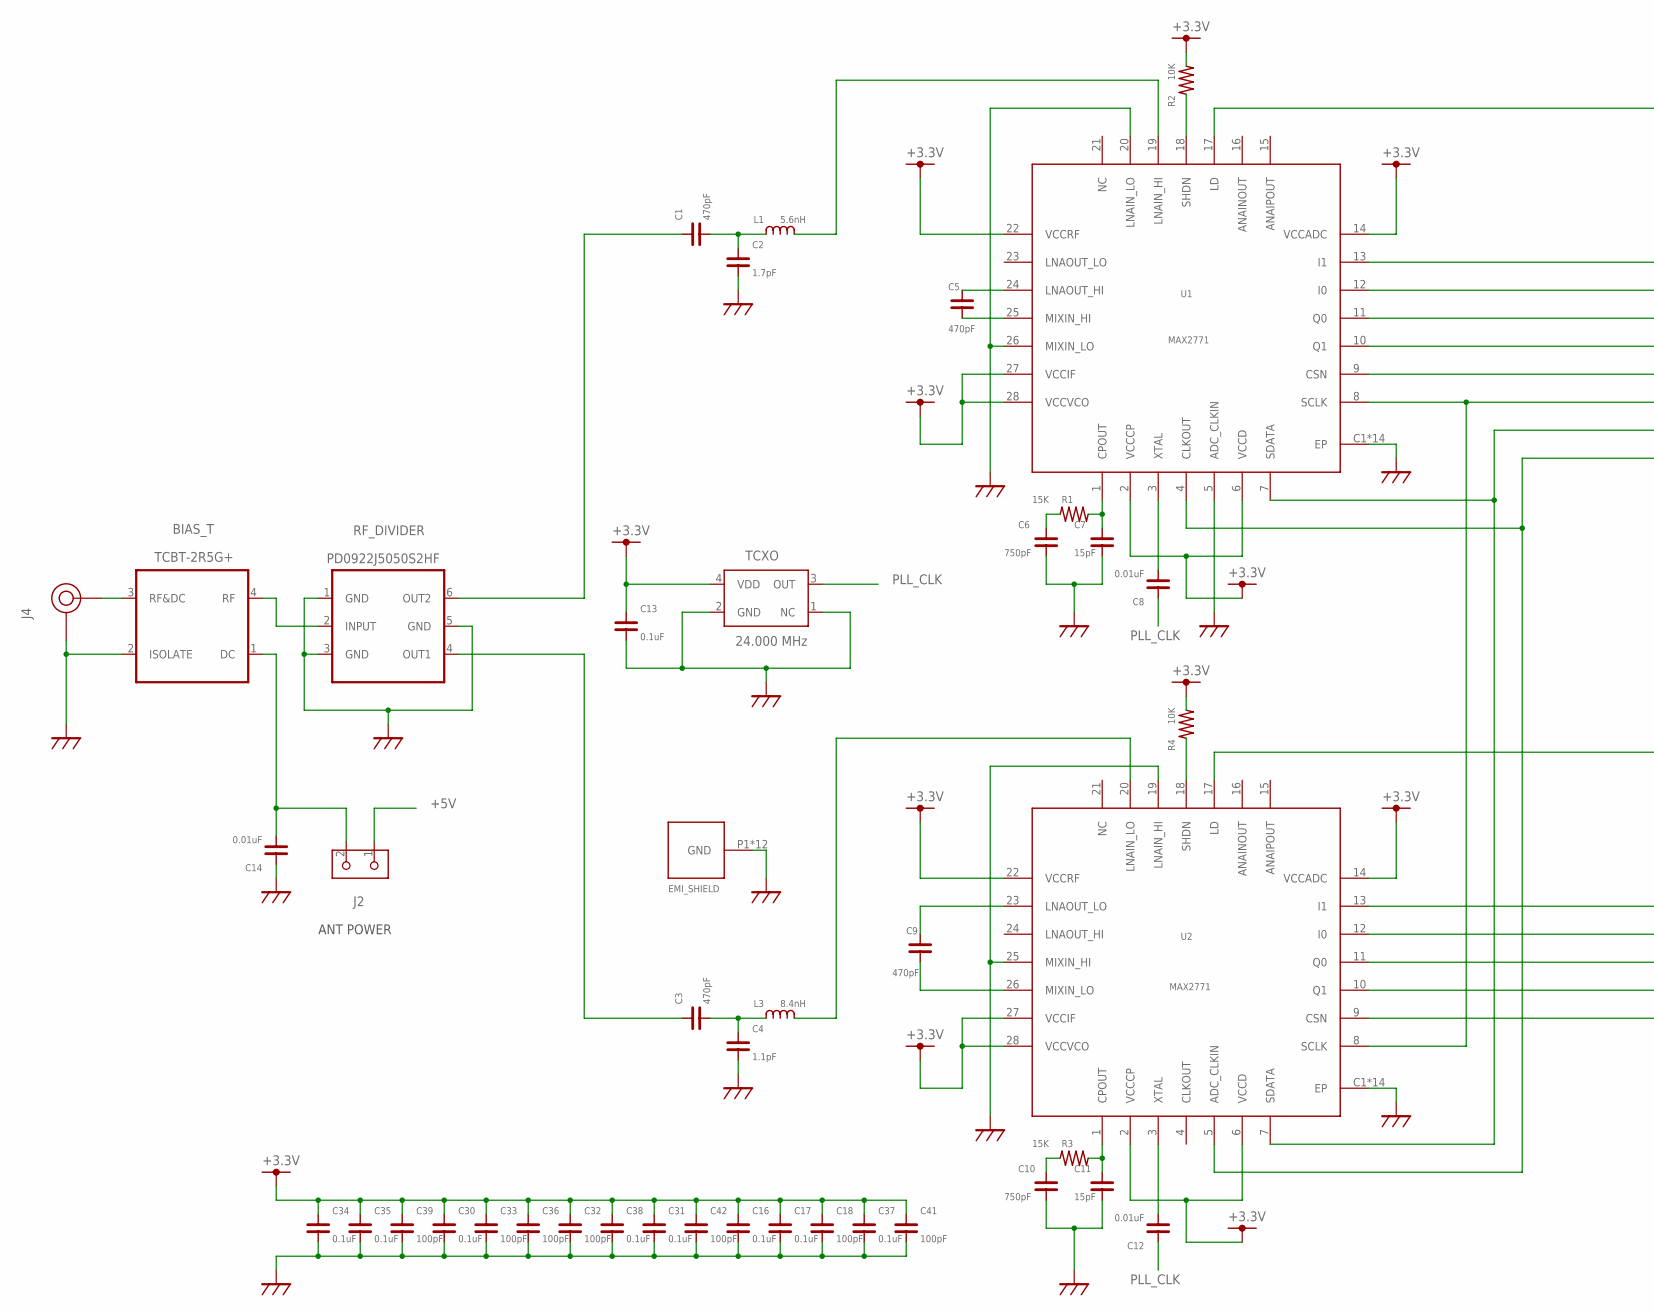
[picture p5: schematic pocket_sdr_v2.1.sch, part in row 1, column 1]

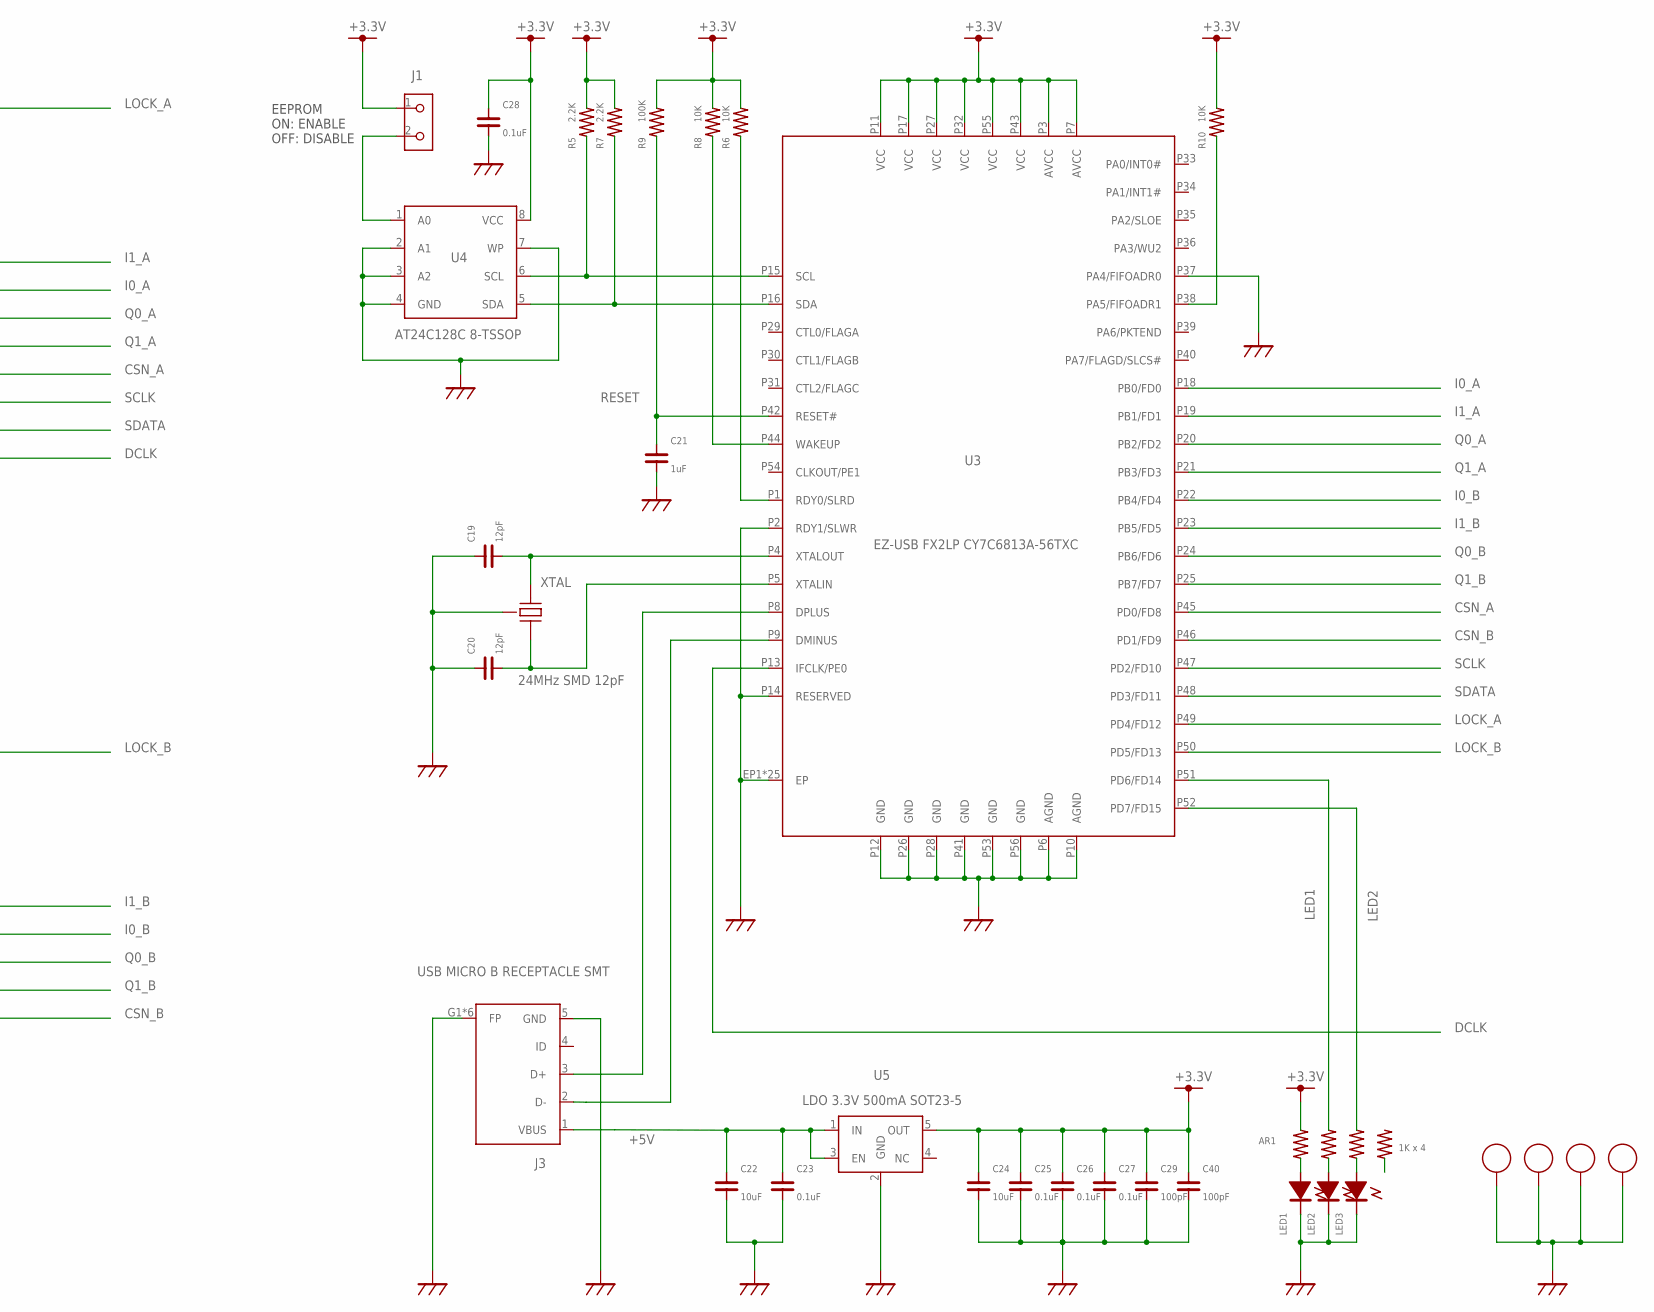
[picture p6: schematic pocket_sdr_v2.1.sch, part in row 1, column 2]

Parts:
AR1: 1K x 4; EXB28V
BIAS_T: TCBT-2R5G+; BIAS_T
C1, C3, C5, C9: 470pF; C1005
C2: 1.7pF; C1005
C4: 1.1pF; C1005
C6, C10: 750pF; C1005
C7, C11: 15pF; C1005
C8, C12, C14: 0.01uF; C1005
C13, C16, C17, C23, C25, C26, C27, C28, C30, C31, C34, C35, C37, C38: 0.1uF; C1005
C18, C29, C32, C33, C36, C39, C40, C41, C42: 100pF; C1005
C19, C20: 12pF; C1005
C21: 1uF; C1005
C22, C24: 10uF; C3225
J1, J2: PIN HEADER 2MM 2P; PINH-2MM-2P
J3: USB MICRO B RECEPTACLE SMT; MICROUSB
J4: SMA JACK EDGE MNT; SMA-ANG
L1: 5.6nH; C1608
L3: 8.4nH; C1608
LED1: LED1608 GREEN; LED_1608
LED2, LED3: LED1608 BLUE; LED_1608
R1, R3: 15K; C1005
R2, R4, R6, R8, R10: 10K; C1005
R5, R7: 2.2K; C1005
R9: 100K; C1005
RF-SHEILD-CASE: BMI-S-202-F BMI-S-202-C; BMI-S-202
RF_DIVIDER: PD0922J5050S2HF; RF_DIV
TCXO: 24.000 MHz; TCXO
U1, U2: MAX2771; TQFN28
U3: EZ-USB FX2LP CY7C6813A-56TXC; QFN56
U4: AT24C128C 8-TSSOP; TSSOP_8P
U5: LDO 3.3V 500mA SOT23-5; SOT23
U$53, U$54, U$55, U$58: CPAD_2.2MM
XTAL: 24MHz SMD 12pF; XTAL_SMD

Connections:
+3.3V: AR1.2, C13.1, C16.1, C17.1, C18.1, C24.P$1 (1), C25.1, C26.1, C27.1, C28.1, C29.1, C30.1, C31.1, C32.1, C33.1, C34.1, C35.1, C36.1, C37.1, C38.1, C39.1, C40.1, C41.1, C42.1, J1.1, R2.2, R4.2, R5.2, R6.2, R7.2, R8.2, R9.2, R10.2, TCXO.4 (VDD), U1.2 (VCCCP), U1.6 (VCCD), U1.14 (VCCADC), U1.22 (VCCRF), U1.27 (VCCIF), U1.28 (VCCVCO), U2.2 (VCCCP), U2.6 (VCCD), U2.14 (VCCADC), U2.22 (VCCRF), U2.27 (VCCIF), U2.28 (VCCVCO), U3.P3 (AVCC), U3.P7 (AVCC), U3.P11 (VCC), U3.P17 (VCC), U3.P27 (VCC), U3.P32 (VCC), U3.P43 (VCC), U3.P55 (VCC), U4.8 (VCC), U5.5 (OUT)
+5V: C22.P$1 (1), C23.1, J2.1, J3.1 (VBUS), U5.1 (IN), U5.3 (EN)
CSN_A: U1.9 (CSN), U3.P45 (PD0/FD8)
CSN_B: U2.9 (CSN), U3.P46 (PD1/FD9)
DCLK: U1.4 (CLKOUT), U2.5 (ADC_CLKIN), U3.P13 (IFCLK/PE0)
FIFOADR1: R10.1, U3.P38 (PA5/FIFOADR1)
GND: BIAS_T.2 (ISOLATE), C2.1, C4.2, C6.2, C7.2, C10.2, C11.2, C13.2, C14.1, C16.2, C17.2, C18.2, C19.1, C20.1, C21.2, C22.P$2 (2), C23.2, C24.P$2 (2), C25.2, C26.2, C27.2, C28.2, C29.2, C30.2, C31.2, C32.2, C33.2, C34.2, C35.2, C36.2, C37.2, C38.2, C39.2, C40.2, C41.2, C42.2, J3.5 (GND), J3.G1 (FP), J3.G2 (FP), J3.G3 (FP), J3.G4 (FP), J3.G5 (FP), J3.G6 (FP), J4.P2 (GND), J4.P3 (GND), J4.P4 (GND), J4.P5 (GND), LED1.2, LED2.2, LED3.2, RF-SHEILD-CASE.P1, RF-SHEILD-CASE.P2, RF-SHEILD-CASE.P3, RF-SHEILD-CASE.P4, RF-SHEILD-CASE.P5, RF-SHEILD-CASE.P6, RF-SHEILD-CASE.P7, RF-SHEILD-CASE.P8, RF-SHEILD-CASE.P9, RF-SHEILD-CASE.P10, RF-SHEILD-CASE.P11, RF-SHEILD-CASE.P12, RF_DIVIDER.1 (GND), RF_DIVIDER.3 (GND), RF_DIVIDER.5 (GND), TCXO.1 (NC), TCXO.2 (GND), U1.5 (ADC_CLKIN), U1.20 (LNAIN_LO), U1.26 (MIXIN_LO), U1.C1 (EP), U1.C2 (EP), U1.C3 (EP), U1.C4 (EP), U1.EP, U1.V1 (EP), U1.V2 (EP), U1.V3 (EP), U1.V4 (EP), U1.V5 (EP), U1.V6 (EP), U1.V7 (EP), U1.V8 (EP), U1.V9 (EP), U2.19 (LNAIN_HI), U2.25 (MIXIN_HI), U2.C1 (EP), U2.C2 (EP), U2.C3 (EP), U2.C4 (EP), U2.EP, U2.V1 (EP), U2.V2 (EP), U2.V3 (EP), U2.V4 (EP), U2.V5 (EP), U2.V6 (EP), U2.V7 (EP), U2.V8 (EP), U2.V9 (EP), U3.EP1 (EP), U3.EP2 (EP), U3.EP3 (EP), U3.EP4 (EP), U3.EP5 (EP), U3.P2 (RDY1/SLWR), U3.P6 (AGND), U3.P10 (AGND), U3.P12 (GND), U3.P14 (RESERVED), U3.P26 (GND), U3.P28 (GND), U3.P37 (PA4/FIFOADR0), U3.P41 (GND), U3.P53 (GND), U3.P56 (GND), U3.P$1 (EP), U3.P$2 (EP), U3.P$3 (EP), U3.P$4 (EP), U3.P$5 (EP), U3.P$6 (EP), U3.P$7 (EP), U3.P$8 (EP), U3.P$9 (EP), U3.P$10 (EP), U3.P$11 (EP), U3.P$12 (EP), U3.P$13 (EP), U3.P$14 (EP), U3.P$15 (EP), U3.P$16 (EP), U3.P$17 (EP), U3.P$18 (EP), U3.P$19 (EP), U3.P$20 (EP), U4.2 (A1), U4.3 (A2), U4.4 (GND), U4.7 (WP), U5.2 (GND), U$53.EP, U$54.EP, U$55.EP, U$58.EP, XTAL.P2 (GND), XTAL.P4 (GND)
I0_A: U1.12 (I0), U3.P18 (PB0/FD0)
I0_B: U2.12 (I0), U3.P22 (PB4/FD4)
I1_A: U1.13 (I1), U3.P19 (PB1/FD1)
I1_B: U2.13 (I1), U3.P23 (PB5/FD5)
LED1: AR1.4, U3.P51 (PD6/FD14)
LED2: AR1.6, U3.P52 (PD7/FD15)
LOCK_A: U1.17 (LD), U3.P49 (PD4/FD12)
LOCK_B: U2.17 (LD), U3.P50 (PD5/FD13)
unnamed: C5.2, U1.25 (MIXIN_HI)
unnamed: C5.1, U1.24 (LNAOUT_HI)
unnamed: BIAS_T.3 (RF&DC), J4.P1 (RF)
unnamed: BIAS_T.4 (RF), RF_DIVIDER.2 (INPUT)
unnamed: BIAS_T.1 (DC), C14.2, J2.2
unnamed: R6.1, U3.P1 (RDY0/SLRD)
unnamed: AR1.3, LED2.1 (+)
unnamed: C1.2, C2.2, L1.1
unnamed: C8.2, U1.3 (XTAL)
unnamed: L1.2, U1.19 (LNAIN_HI)
unnamed: AR1.1, LED1.1 (+)
unnamed: C1.1, RF_DIVIDER.6 (OUT2)
unnamed: C9.2, U2.26 (MIXIN_LO)
unnamed: C9.1, U2.23 (LNAOUT_LO)
unnamed: C19.2, U3.P4 (XTALOUT), XTAL.P1 (XTAL1)
unnamed: R2.1, U1.18 (SHDN)
unnamed: J3.3 (D+), U3.P8 (DPLUS)
unnamed: C20.2, U3.P5 (XTALIN), XTAL.P3 (XTAL2)
unnamed: AR1.5, LED3.1 (+)
unnamed: C7.1, R1.2, U1.1 (CPOUT)
unnamed: C6.1, R1.1
unnamed: C11.1, R3.2, U2.1 (CPOUT)
unnamed: R7.1, U3.P16 (SDA), U4.5 (SDA)
unnamed: R5.1, U3.P15 (SCL), U4.6 (SCL)
unnamed: R8.1, U3.P44 (WAKEUP)
unnamed: C10.1, R3.1
unnamed: J3.2 (D-), U3.P9 (DMINUS)
unnamed: J1.2, U4.1 (A0)
unnamed: C3.1, RF_DIVIDER.4 (OUT1)
unnamed: C3.2, C4.1, L3.1
unnamed: L3.2, U2.20 (LNAIN_LO)
unnamed: R4.1, U2.18 (SHDN)
unnamed: C12.2, U2.3 (XTAL)
PLL_CLK: C8.1, C12.1, TCXO.3 (OUT)
Q0_A: U1.11 (Q0), U3.P20 (PB2/FD2)
Q0_B: U2.11 (Q0), U3.P24 (PB6/FD6)
Q1_A: U1.10 (Q1), U3.P21 (PB3/FD3)
Q1_B: U2.10 (Q1), U3.P25 (PB7/FD7)
RESET: C21.1, R9.1, U3.P42 (RESET#)
SCLK: U1.8 (SCLK), U2.8 (SCLK), U3.P47 (PD2/FD10)
SDATA: U1.7 (SDATA), U2.7 (SDATA), U3.P48 (PD3/FD11)

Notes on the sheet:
ANT POWER
EEPROM ON: ENABLE OFF: DISABLE

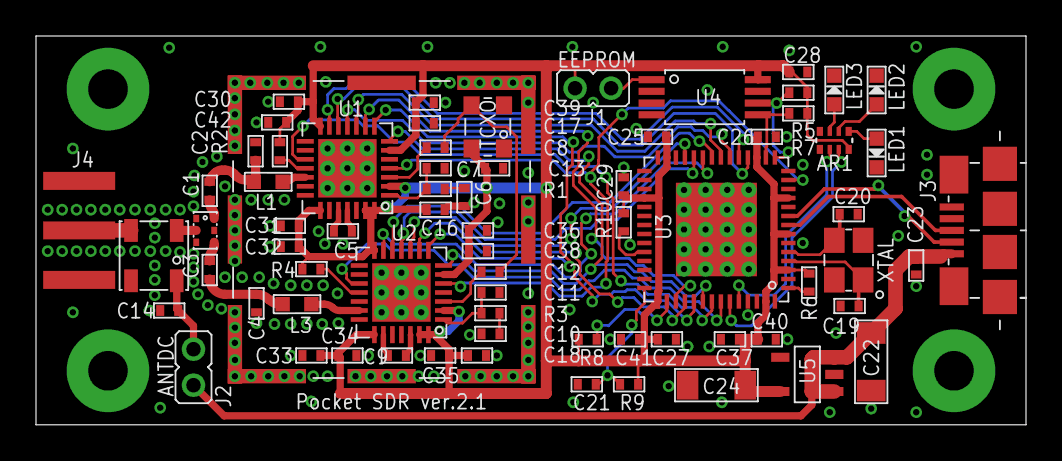
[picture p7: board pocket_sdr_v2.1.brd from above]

Board: 2 copper layers, 55.0 x 21.6 mm, 75 parts (0 on the bottom side), 56 nets.

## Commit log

2023-12-21 Switch to KiCAD 7+
    Eagle is being discontinued in the future. For the NEO variant of PocketSDR (type-C), the Eagle version has been archived.
    [pocket_sdr_case.f3d, pocket_sdr_label.xlsx, pocket_sdr_v2.1.brd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]
2023-12-21 Add BOM & Gerber
    [BOM_pocket_sdr_v2.1_NEO.xlsx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]
2023-12-21 added MICROSMD010 to list
    [BOM_pocket_sdr_v2.1_NEO.xlsx]
2023-12-21 Switch to KiCAD 7+
    [pocket_sdr_v2.1.kicad_pcb]
2023-12-22 Switch to KiCAD 7+
    Updated board dimensions
    [pocket_sdr_v2.1.kicad_pcb]
